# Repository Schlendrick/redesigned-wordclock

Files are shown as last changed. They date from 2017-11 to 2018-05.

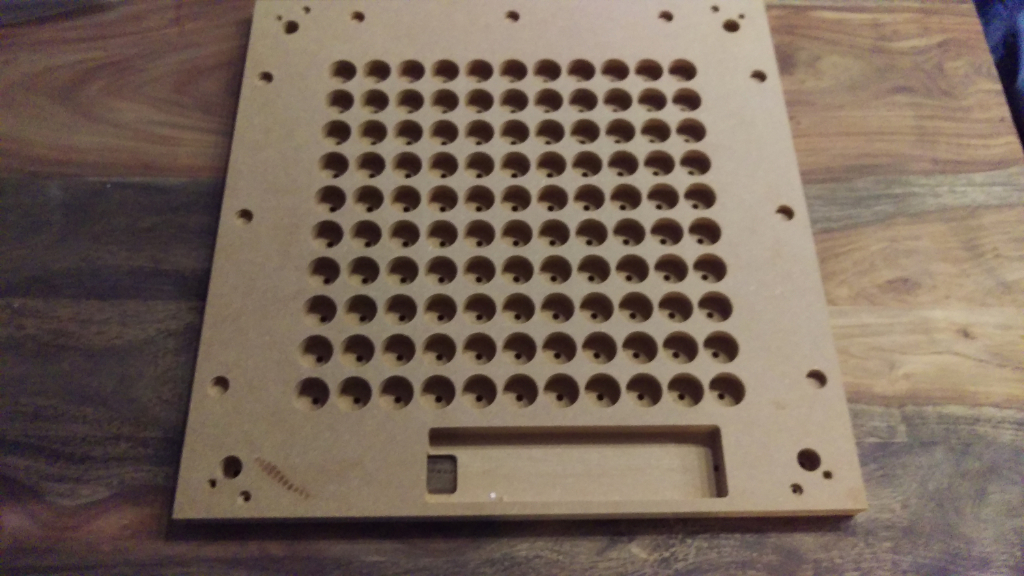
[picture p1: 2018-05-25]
Gehäuse/v1.0/IMAG0333.jpg

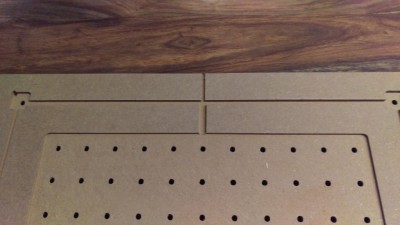
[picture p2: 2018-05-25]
Gehäuse/v1.0/IMAG0337.jpg

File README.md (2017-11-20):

# rgb_wordclock_redesigned

Wordclock based on the popular WS2812B RGB LED strips with the ESP32 Controller.

## ToDo

- [x] Replace DCF77 recipient (Onboard Wifi sync)
- [ ] Turn the clock automatic off at night
- [ ] Show the temperature (Onboard Temperatur Sensor)
- [ ] Smartphone app to control the clock
- [ ] Replace WS2812B to newer Version LED (e.g.WS2813) to save energy

## Build

## Known Issues

## LED Mapping

`alt_layout1.h`

```
111                                        110                      .                        .

       99 100 101 102 103 104 105 106 107 108 109                      E S K I S T A F Ü N F
       98  97  96  95  94  93  92  91  90  89  88                      Z E H N Z W A N Z I G
       77  78  79  80  81  82  83  84  85  86  87                      D R E I V I E R T E L
       76  75  74  73  72  71  70  69  68  67  66                      V O R F U N K N A C H
       55  56  57  58  59  60  61  62  63  64  65                      H A L B A E L F Ü N F
       54  53  52  51  50  49  48  47  46  45  44                      E I N S X Ä M Z W E I
       33  34  35  36  37  38  39  40  41  42  43                      D R E I A U J V I E R
       32  31  30  29  28  27  26  25  24  23  22                      S E C H S N L A C H T
       11  12  13  14  15  16  17  18  19  20  21                      S I E B E N Z W Ö L F
       10  9   8   7   6   5   4   3   2    1   0                      Z E H N E U N K U H R

112                                        113                      .                         .
```

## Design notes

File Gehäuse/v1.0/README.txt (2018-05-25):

MY EDIT:

http://diskussion.christians-bastel-laden.de/viewtopic.php?f=11&t=2673
"Nun aber ein Paar Bilder des gefrästen Rahmens. Material ist MDF in 22mm stärke und ausgelegt für ws2812b leds."

################
#    Lizenz    #
################

Dieser Rahmen wird unter der Creative Commons Lizenz "CC BY-NC-SA" veröffentlicht.
Diese Lizenz erlaubt es euch den Rahmen zu benutzen zu verändern, darauf aufzubauen und zu erweitern. Sämtliche Änderungen müssen jedoch unter der gleichen Lizenz mit Verweis auf diese Basis veröffentlicht und anderen zugänglich gemacht werden.

Eine kommerzielle Nutzung ist nicht gestattet.

Weiter Details zur Lizenz findet Ihr unter: https://creativecommons.org/licenses/by-nc-sa/4.0/

########################################
#    Aufbereitung für die Fertigung    #
########################################

Die Dateien sind für einen 50x50cm Rahmen.

Ihr findet im Archive 2 DXF Dateien. In den Dateien sind die einzelnen Bereiche des Rahmens gruppiert. Hier findet ihr nun die jeweiligen Zieltiefen für die jeweiligen Ebenen. Diese Daten benötigt ihr zum vorbereiten der Zeichnung zum fräsen auf eurer Fräse.

Bei den Zieltiefen gehe ich von einer 22mm starken MDF Platte aus.

Tiefe 0 = Plan mit Oberfläche. Tiefe -22 = komplett durchgefräst.

Datei: Wortuhr_rahmen_front_ws2812b.dxf

 - Aufhaengung aussen	: Zieltiefe -5 mm
 - Aufhaengung innen	: Zieltiefe -22 mm
 - LED			: Zieltiefe -20 mm(gefräst von vorne), oder Zieltiefe -6.5mm wenn von der Rückseite gefräst
 - Minuten LED		: Zieltiefe -20 mm(gefräst von vorne), oder Zieltiefe -6.5mm wenn von der Rückseite gefräst
 - Lichtkegel		: Zieltiefe -16.5mm
 - Lichtkegel Minuten	: Zieltiefe -16.5mm
 - Magnete Aussen 	: Zieltiefe -3 mm
 - Magnete Innen	: Zieltiefe -8 mm
 - Elektronikbox	: Zieltiefe -19 mm

Datei: Wortuhr_rahmen_back.dxf

 - LED flaeche		: Zieltiefe -2.5 mm
 - Strombuchse		: Zieltiefe -3.5 mm
 - LDR Kanal	 	: Zieltiefe -2.5 mm
 - Kabelkanal		: Zieltiefe -2.5 mm
 - Elektronik		: Zieltiefe -19 mm

################
#    Donate    #
################

Sollte euch das Gehäuse gefallen, würde ich mich über ein Bier freuen. 

https://www.paypal.me/kstenders

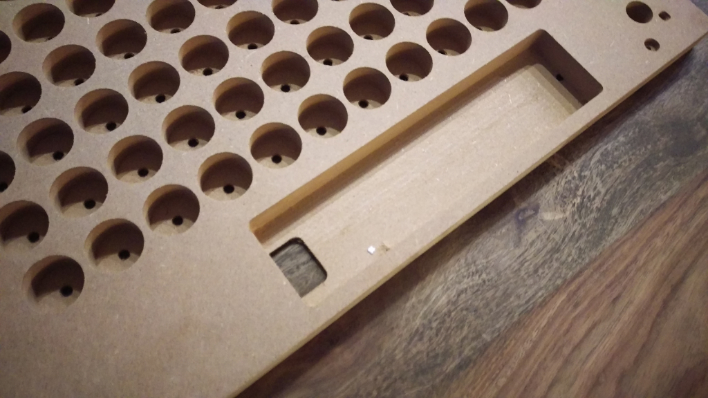
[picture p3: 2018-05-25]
Gehäuse/v1.0/IMAG0334.jpg

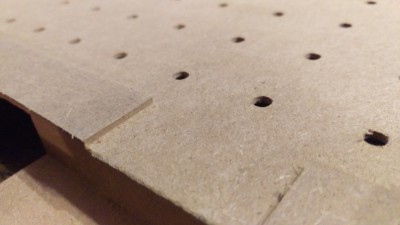
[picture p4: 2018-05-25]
Gehäuse/v1.0/IMAG0336.jpg

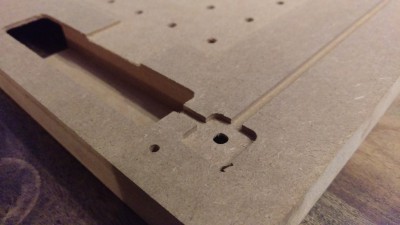
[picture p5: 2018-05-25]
Gehäuse/v1.0/IMAG0335.jpg

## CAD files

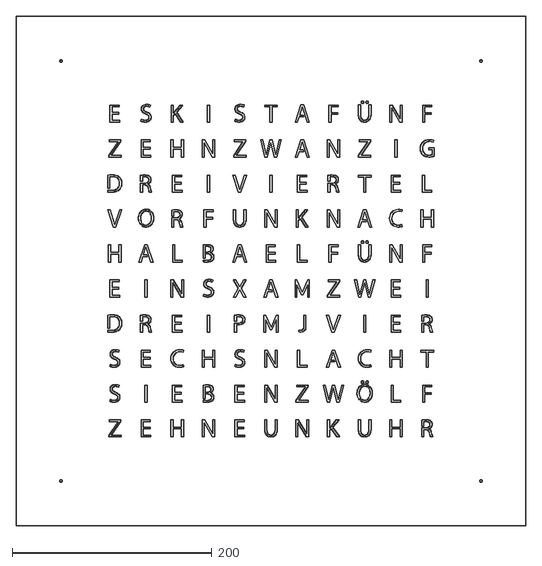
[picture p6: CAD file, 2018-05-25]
Frontplatte/500x500 DE mit 4mm Rand/500x500_CLT_DE_Laser_4_rand.dxf
510.0 x 510.0

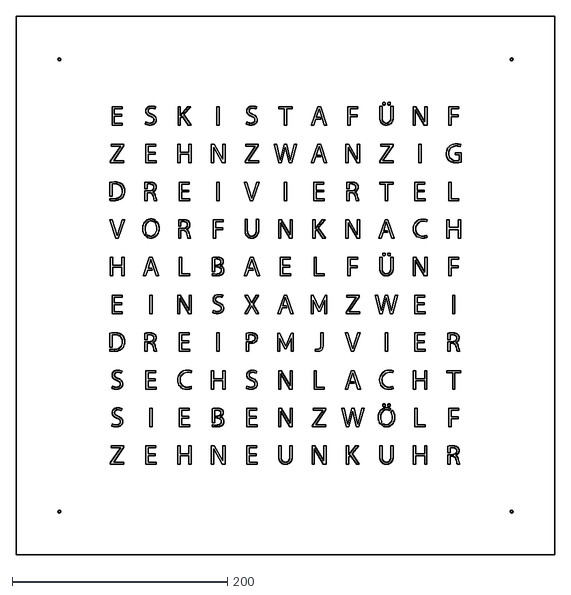
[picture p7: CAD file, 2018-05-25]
Frontplatte/500x500_CLT_DE_Laser/500x500_CLT_DE_Laser_4.dxf
500.0 x 500.0

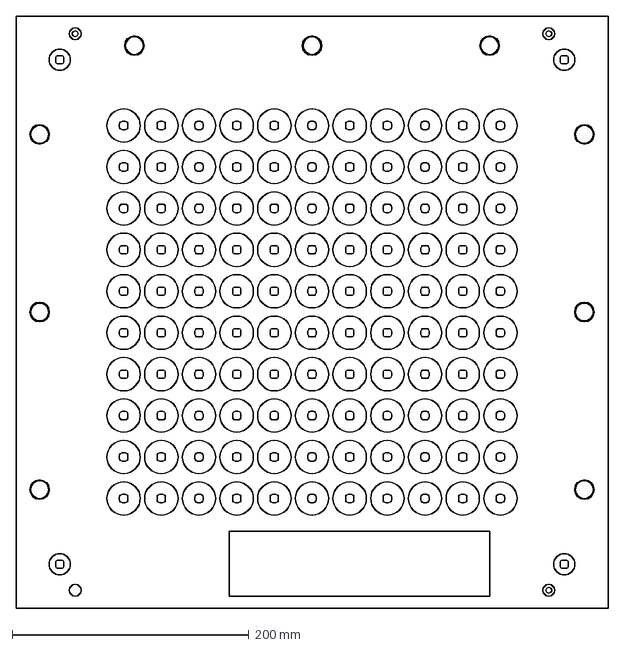
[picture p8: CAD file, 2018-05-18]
Gehäuse/v1.0/Wortuhr_rahmen_front_ws2812b.dxf
500.0 x 500.0 mm

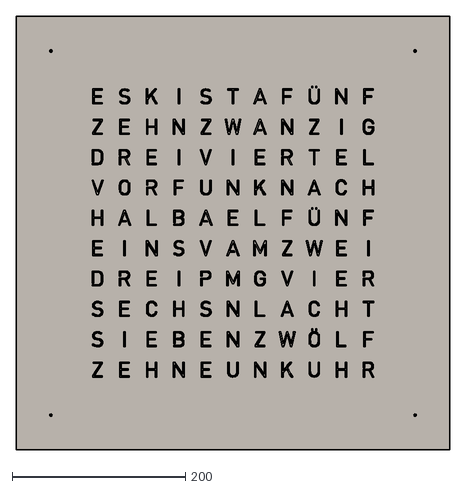
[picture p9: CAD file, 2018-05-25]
Frontplatte/500x500_CLT_DE_Laser/500x500_CLT_DE_Laser_7.dxf
500.0 x 500.0

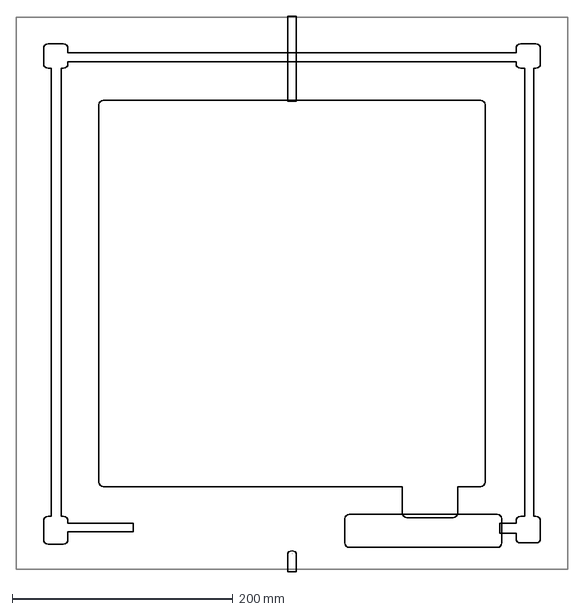
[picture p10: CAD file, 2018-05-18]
Gehäuse/v1.0/Wortuhr_rahmen_back.dxf
500.0 x 503.0 mm

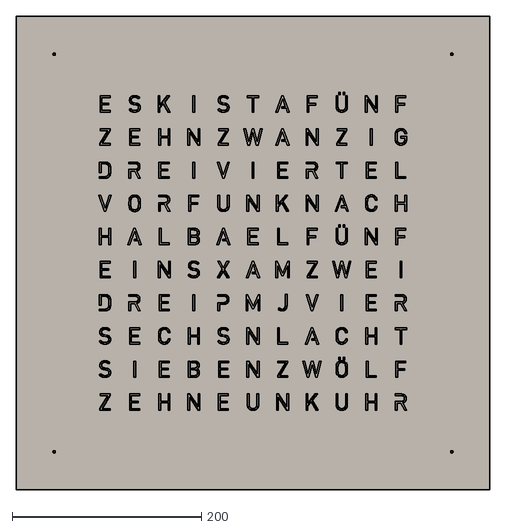
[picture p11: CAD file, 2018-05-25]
Frontplatte/500x500_CLT_DE_Laser/500x500_CLT_DE_Laser_1.dxf
500.0 x 500.0

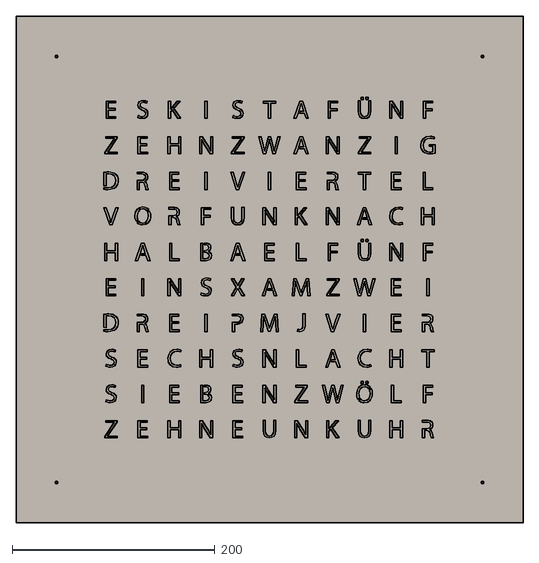
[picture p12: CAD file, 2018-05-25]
Frontplatte/500x500_CLT_DE_Laser/500x500_CLT_DE_Laser_6.dxf
500.0 x 500.0

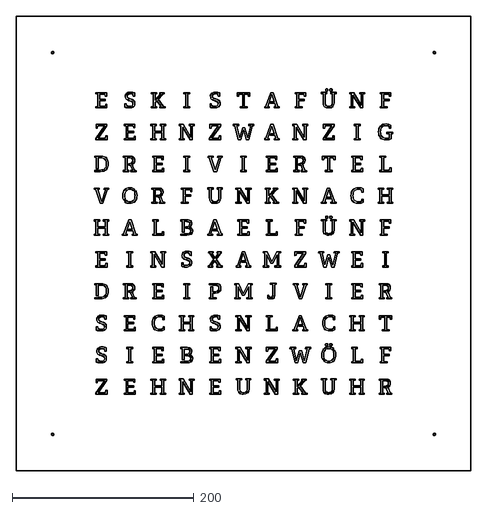
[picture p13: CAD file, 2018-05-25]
Frontplatte/500x500_CLT_DE_Laser/500x500_CLT_DE_Laser_2.dxf
500.0 x 500.0

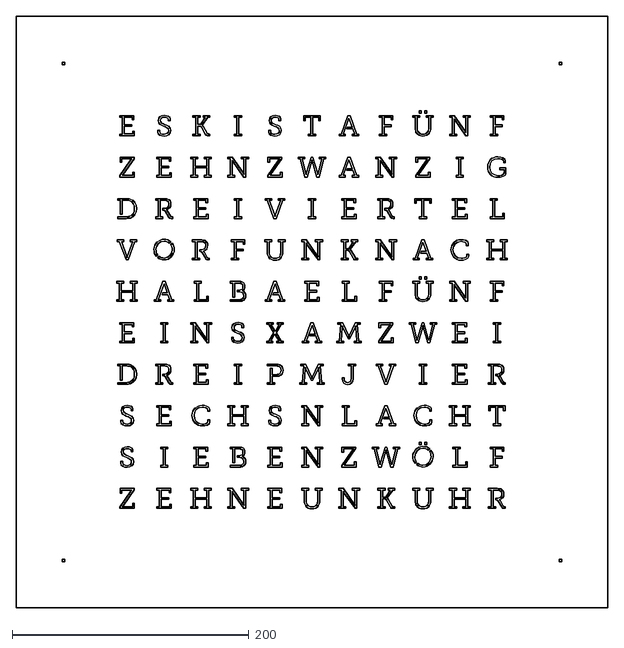
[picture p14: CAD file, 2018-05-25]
Frontplatte/500x500_CLT_DE_Laser/500x500_CLT_DE_Laser_5.dxf
500.0 x 500.0

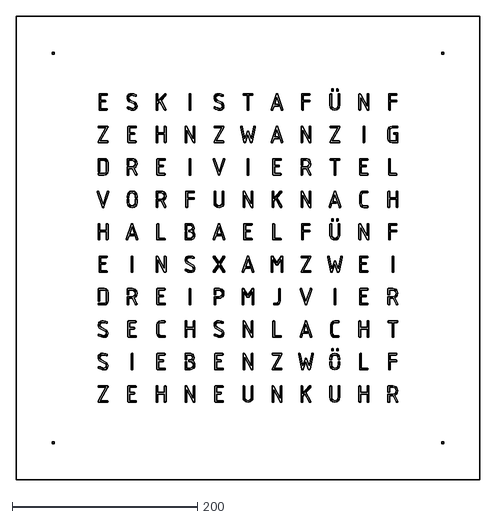
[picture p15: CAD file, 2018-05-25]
Frontplatte/500x500_CLT_DE_Laser/500x500_CLT_DE_Laser_3.dxf
500.0 x 500.0

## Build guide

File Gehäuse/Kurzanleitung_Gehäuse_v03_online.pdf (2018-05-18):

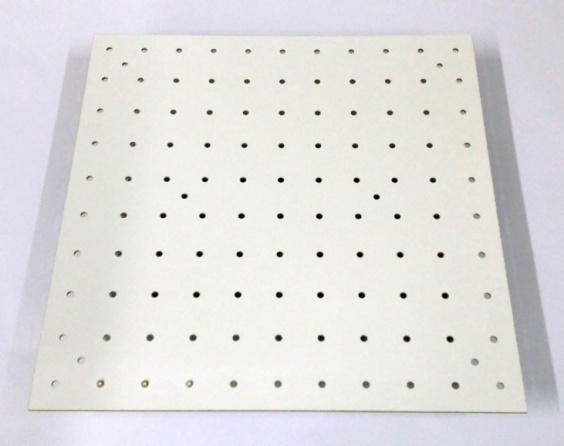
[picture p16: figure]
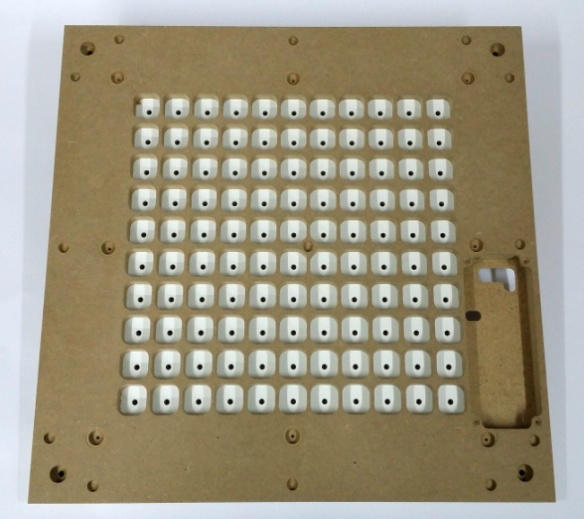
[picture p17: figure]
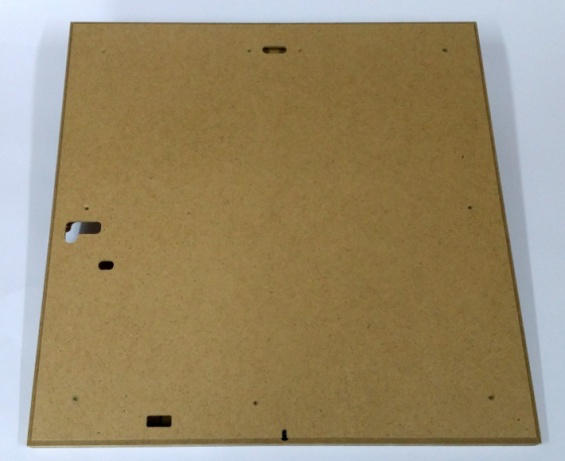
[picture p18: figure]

10.03.2015 1

# 45er v03 Gehäuse

Vielen Dank, dass Sie sich für dieses Gehäuse aus dem Hause Kellys Finest entschieden haben.

Ich wünsche Ihnen viel Freude an diesem Produkt.

Bevor Sie mit dem Bau beginnen:

- Lesen Sie vor der ersten Benutzung diese Anleitung sorgfältig durch. So werden Sie mit Ihrem neuen Gehäuse vertraut und erhalten wichtige Tipps für den Zusammenbau.
- Für Schäden die aus der Nichtbeachtung dieser Bedienungsanleitung verursacht werden, übernehmen wir keine Haftung.
- Beachten Sie besonders die Montagehinweise.
- Bewahren Sie diese Anleitung gut auf.

Lieferumfang 45er v03 Gehäuse:

- Gehäuse Korpus MDF 450x450x19mm
- LED Träger HDF 3mm
- Rückwand HDF 440x440x3mm
- 1 Anleitung

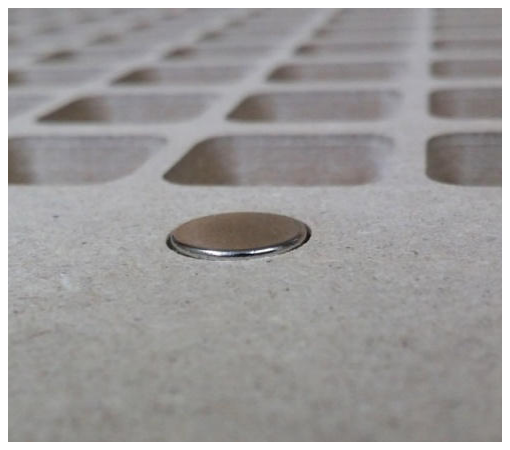
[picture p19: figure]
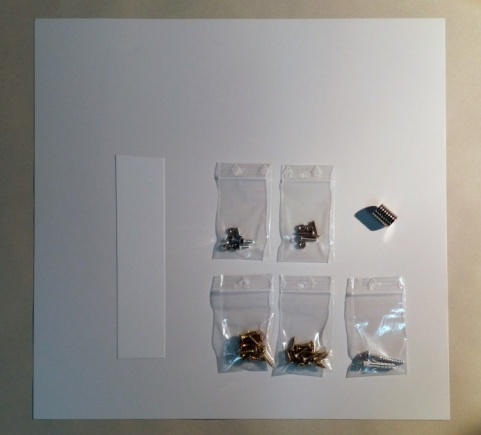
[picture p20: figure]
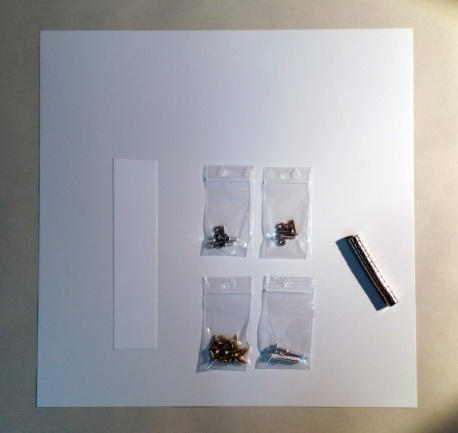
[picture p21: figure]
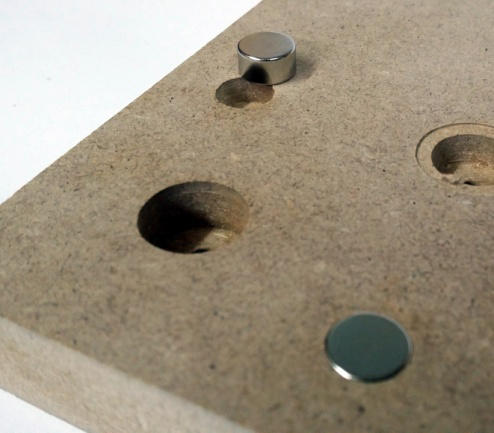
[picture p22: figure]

10.03.2015 2

zusätzlich im "45er v03 Gehäuse Zubehörpaket":

- Wandbefestigung Schraube + Dübel
- 8 Magnete Ø 12mm x 2mm
- 8x Schrauben als Basis für Magnete
- 9x Schrauben zur Rückwandbefestigung
- 6x Schrauben zur LED Trägerbefestigung
- 3x Linsenkopf Schrauben + Muttern für Tasterbetätigung
- 4x Senkkopf Schrauben + Muttern für v03 Befestigung
- Diffusionsfolie

oder im "45er -Stahl- v03 Gehäuse Zubehörpaket":

- Wandbefestigung Schraube + Dübel
- 13 Magnete Ø 10mm x 5mm
- 9x Schrauben zur Rückwandbefestigung
- 6x Schrauben zur LED Trägerbefestigung
- 3x Linsenkopf Schrauben + Muttern für Taster
- 4x Senkkopf Schrauben + Muttern für v03 Befestigung
- Diffusionsfolie

10.03.2015 3

Eigenschaften:

- passgenaues MDF Gehäuse zum Bau einer Wortuhr
- vom Gehäuse getrennter LED Träger, dadurch leichterer Aufbau und einfache Anpassbarkeit auf unterschiedliche LEDs --> mehr Passgenauigkeit
- speziell für 45ger Front mit v03 Nachbau Platine
- inklusive Rückwand zur Abdeckung/Schutz der Elektronik
- höhenjustierbare Aufnahme der Magneten. Der Abstand zur Front kann so eingestellt werden, das ein kleiner Luftspalt zwischen Gehäuse und Front vorhanden ist. Dadurch wird die Gefahr der Ablösung der Folie stark gemindert da kein permanenter Zug auf die Folie wirkt.
- durch die Verklebung der 2mm Magnete direkt auf der Front und die entsprechenden Vertiefungen im Gehäuse wird ein Formschluss erreicht und die Front kann nicht verrutschen
- oder wahlweise für schwere magnetische Fronten, Aufnahme für 13 stärkere Magnete zum Einkleben
- FTDI Anschluss zum Programmieren zugänglich von Hinten
- Standardmäßig zentraler Aufhängungspunkt zur Wandbefestigung

Mit Zubehörpaket zusätzlich:

- Satz Magnete Ø 12mm x 2mm für Befestigung einer Acrylfront (höhenverstellbar)
- oder Satz Magnete Ø 10mm x 5mm für schwere magnetische Fronten
- Hochwertige Diffusionsfolie für die Buchstabenmatrix und die Eck LEDs
- alle benötigten Schrauben zum Einbau der Elektronik und der Magnete
- Lösung um die Taster der v03 von außen bedienen zu können

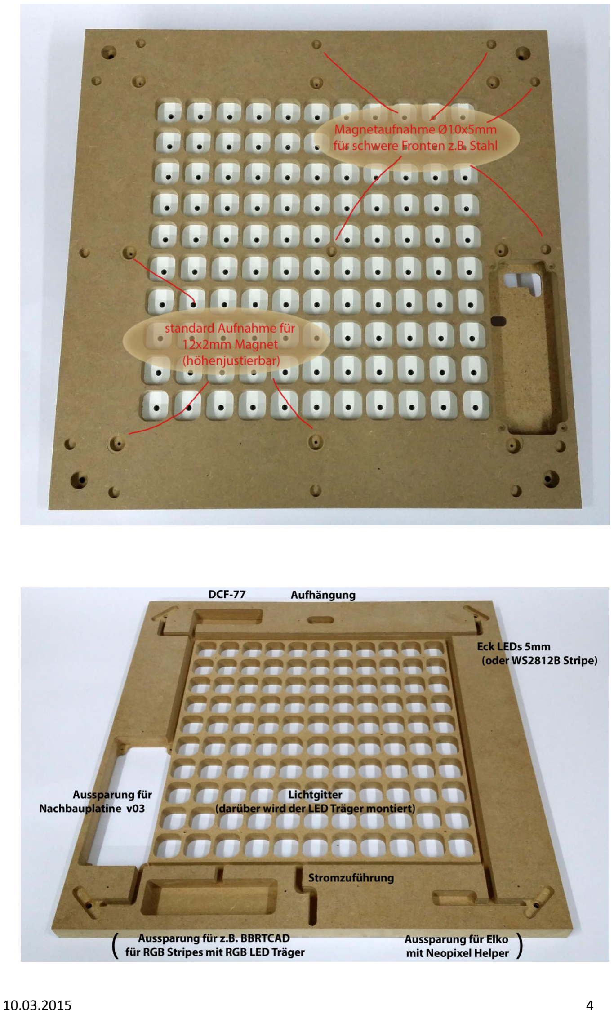
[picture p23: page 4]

10.03.2015 4

10.03.2015

### Magnete ! Hinweise für den sicheren Umgang

Verschlucken
Kinder können kleine Magnete verschlucken.
Wenn mehrere Magnete verschluckt werden, können die im Darm festsetzen und lebensgefährli
verursachen.
Magnete sind kein
nicht in die Hände von Kindern gelangen.

Elektroleitfähigkeit
Magnete sind aus Metall und leiten elektrischen Str Kinder können versuchen, Magnete in eine Steckdose und da
Magnete sind kein Spielzeug! Stellen Sie sicher, da nicht in die Hände von Kindern gelangen.

Quetschungen
Große Magnete haben eine sehr starke Anziehungskraf Bei unvorsichtiger Handhabung können Sie sich die F Haut
Quetschungen und Blutergüssen an den betroffenen St führen.
Knochenbrüche verurs
Tragen Sie bei der Handhabung von größeren Magneten

Herzschrittmacher
Magnete können die Funktion von Herzschrittmachern implantierten Defibrillatoren beeinflussen.
Ein Herzschrittmacher kann in den Testmodus geschal und Unwohlsein verursachen.
Ein Defibrillator funktioni
Halten Sie als Träger solcher Geräte einen genü
zu Magneten ein.
Warnen Sie Träger solcher Geräte vor der Annäherung

### Hinweise für den sicheren Umgang

Verschlucken
Kinder können kleine Magnete verschlucken.
Wenn mehrere Magnete verschluckt werden, können die
im Darm festsetzen und lebensgefährliche Komplikationen verursachen.
Magnete sind kein Spielzeug! Stellen Sie sicher, dass die Magnete nicht in die Hände von Kindern gelangen.

Elektroleitfähigkeit
Magnete sind aus Metall und leiten elektrischen Str Kinder können versuchen, Magnete in eine Steckdose bei einen Stromschlag erleiden.
Magnete sind kein Spielzeug! Stellen Sie sicher, da nicht in die Hände von Kindern gelangen.

Quetschungen
Große Magnete haben eine sehr starke Anziehungskraf Bei unvorsichtiger Handhabung können Sie sich die F zwischen zwei Magneten einklemmen. Das kann zu Quetschungen und Blutergüssen an den betroffenen St Sehr große Magnete können durch ihre Kraft Knochenbrüche verursachen.
dicke Schutzhandschuhe

Herzschrittmacher
Magnete können die Funktion von Herzschrittmachern implantierten Defibrillatoren beeinflussen.
Ein Herzschrittmacher kann in den Testmodus geschal und Unwohlsein verursachen.
Ein Defibrillator funktioniert unter Umständen nicht mehr. Halten Sie als Träger solcher Geräte einen genü
zu Magneten ein.
an Magnete.

5

se sich

om.
zu stecken

ss die Magnete

t.
inger oder

ellen

und

tet werden

n nicht mehr.
genden Abstand

10.03.2015

Schwere Gegenstände
Zu hohe oder ruckartige Belastungen, Ermüdungsersch sowie Materialf
oder Magneth
Herunterfallende Gegenstände können zu
führen.
Die angegebene Haftkraft wird nur unter idealen Bed erreicht. Rechnen Sie ein
Verwenden Sie Magnete nicht an Orten, wo bei Materi kommen können.

Metall
Neodym
können sie zersplittern.
Scharfkantige Splitter können meter
we
Vermeide
Tragen Sie bei der Handhabung von größe Schutzbrille.
Achten Sie darauf, dass umstehende Personen ebenfal

Magnetisches Feld
Magnete erzeugen ein weit reichendes, starkes Magne können unter anderem Fernseher und Laptops, Compute Festplatten, Kreditkarten und EC
mechanische Uhren, Hörgeräte und Lautsprecher besch Halten
die durch starke
Beachten Sie unsere Tabelle mit empfohlenen Abständ

Schwere Gegenstände
Zu hohe oder ruckartige Belastungen, Ermüdungsersch
sowie Materialfehler können dazu führen, dass sich ein Magnet oder Magnethaken von seinem Haftgrund löst. Herunterfallende Gegenstände können zu schweren Verletzungen

Die angegebene Haftkraft wird nur unter idealen Bed
erreicht. Rechnen Sie einen hohen Sicherheitsfaktor ein. alversagen Personen zu Schaden

-Splitter
Neodym-Magnete sind spröde. Wenn zwei Magnete kollidieren, können sie zersplittern.
Scharfkantige Splitter können meterweit weg geschleudert rden und Ihre Augen verletzen.
Vermeiden Sie Kollisionen von Magneten.
Tragen Sie bei der Handhabung von größeren Magneten eine Schutzbrille.
ls geschützt sind oder Abstand halten.

Magnetisches Feld
Magnete erzeugen ein weit reichendes, starkes Magne können unter anderem Fernseher und Laptops, Compute Festplatten, Kreditkarten und EC-Karten, Datenträger, mechanische Uhren, Hörgeräte und Lautsprecher besch Sie Magnete von allen Geräten und Gege
die durch starke Magnetfelder beschädigt werden können. en.

6

einungen

schweren Verletzungen

ingungen

ren Magneten eine

tfeld. Sie
r-

ädigen.
nständen fern,

10.03.2015 7

### Achtung, Montagehinweis:

Bitte beachten Sie vor der Montage folgende Hinweise,

- Die Kernbohrungen für die Schrauben zur Magnetaufnahme sind für Schnellbauschrauben mit dem Durchmesser 4mm gewählt
- Die Kernbohrungen für die Schrauben zur Rückwandbefestigung sind für Schnellbauschrauben mit dem Durchmesser 3mm gewählt
- Die Kernbohrungen für die Schrauben zur Befestigung des Lichtträgers sind für Schnellbauschrauben mit dem Durchmesser 3mm gewählt
- Ein Kabelauslass zur Stromversorgung ist angedeutet aber nicht nach unten ausgeführt um alle Möglichkeiten offen zu halten. Bei Bedarf kann der, an dieser Stelle, dünnwandige Rahmen unten mit einer Bohrung versehen werden.

### Wichtig!

- Die Verschraubung in MDF ist zwar stabil und völlig ausreichend aber man muss alle Schrauben mit viel Gefühl anziehen. Nur ganz leicht anziehen bis nichts mehr wackelt. Das genügt und hält.

### Magnete!

Achtung, Magnete sind sehr spröde. Achten Sie darauf das die Magnete nicht aus Versehen "zusammenschnappen", sie können dabei brechen.

Zum Trennen der aneinander liegenden Magnete schieben Sie sie am besten seitlich auseinander (Scheren). Wichtig dabei ist, dass Sie beide Magnete gut festhalten, damit sie sich nicht gleich wieder verbinden und Ihre Finger einklemmen oder zerbrechen. Benützen Sie dabei keine harten oder scharfen Gegenstände, diese können die Magnete beschädigen.

Tipp! vor dem Einlegen des Magneten Frischhaltefolie unter den Magneten legen. Damit kann beim Verkleben kein Klebstoff aufs Gehäuse laufen und aus Versehen die Magnete ins Gehäuse kleben.

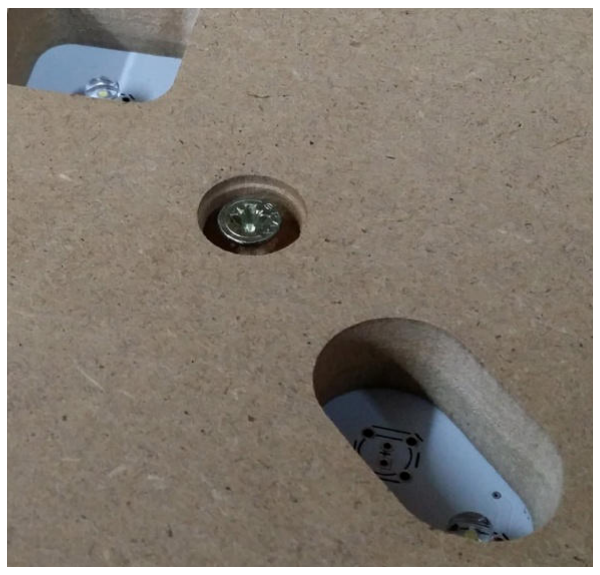
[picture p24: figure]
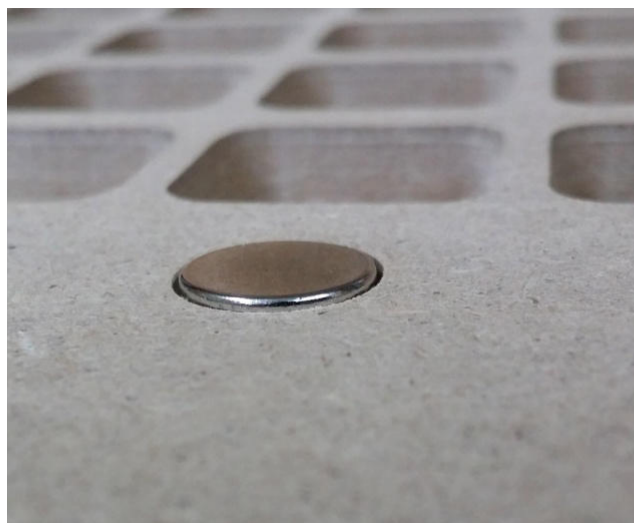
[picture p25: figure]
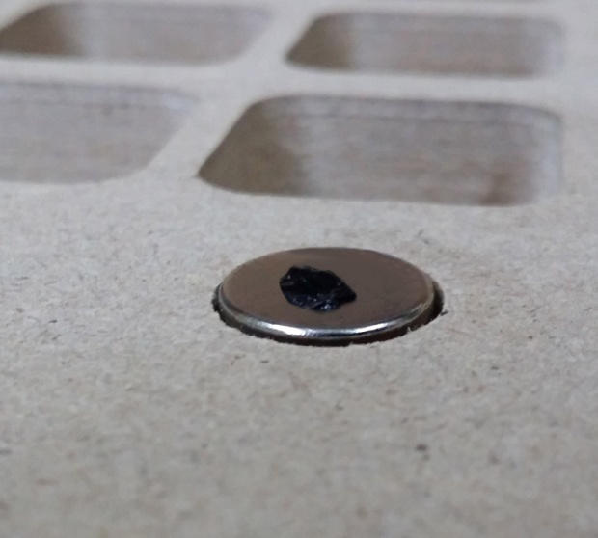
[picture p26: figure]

10.03.2015 8

Einbau der Magnete - Variante A:

Die Schrauben zur Magnetaufnahme(4 x 16mm) so weit eindrehen das sie ca. 1,5mm unterhalb der Oberfläche liegen

Ø 12mm x 2mm Magnete einlegen. Sicherstellen das jeder Magnet ca. 0,5mm über die Oberfläche des Gehäuses hinausragt um genügend Platz für die Diffusionsfolie zu lassen und um die Front mit ein wenig Luft, spannungsfrei Montieren zu können.
Tipp! nach dem Verkleben der Magnete muss noch ein Platt Papier zwischen Gehäuse und Front passen, dann liegen die Magnete gut auf und nichts ist verspannt.

Auf jeden Magneten einen kleinen Tropfen Klebstoff geben ("Silikon zum Kleben" hat sich bei mir bewährt oder Uhu Endfest 300) Aufpassen das es auch wirklich nur ein kleiner Tropfen ist und nicht beim zusammendrücken über den Rand hinausläuft und den Magnet ins Gehäuse einklebt.

Nun die Front passend auf das Gehäuse legen und andrücken. Man sollte nur aufpassen das man die Front gleich gut zentriert auflegt, da ein Verschieben dann nur bedingt möglich ist.

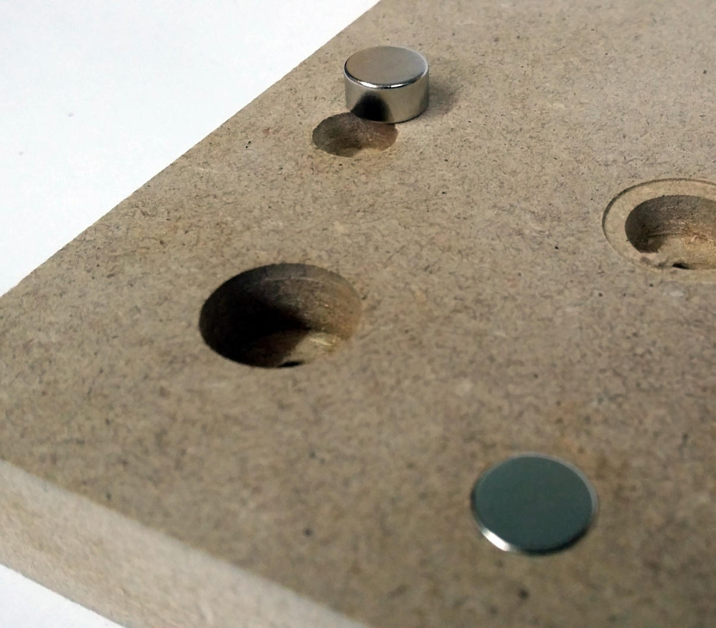
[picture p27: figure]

10.03.2015 9

Variante B:

- Ø 10mm x 5mm Magnete in die entsprechenden Öffnungen pressen. Hier wieder aufpassen, die Magnete können leicht brechen, evtl. ein Stück Holz unterlegen beim Einpressen um die Magnete nicht zu beschädigen.
- Darauf achten das die Magnete ein wenig herausschauen um Platz für die Diffusionsfolie zu lassen. Evtl. mit etwas Klebstoff sichern.
- Da hier kein Formschluss besteht, darauf achten das die Front nicht abrutscht. Evtl. zusätzlich sichern.
- Tipp! Wenn man die Magnete später wieder entfernen möchte, kann man in die Vertiefungen für die 10mm Magnete noch ein kleines Loch bohren (durch bohren). So hat man die Möglichkeit die Magnete später wieder von hinten heraus zu drücken.

Für den Fall das die gewählte Front bereits Metallplätchen aufgeklebt hat sind im Gehäuse um die Magnete herum zusätzliche Vertiefungen angebracht. Somit kann Variante A auch für Kauf-Fronten erweitert werden.

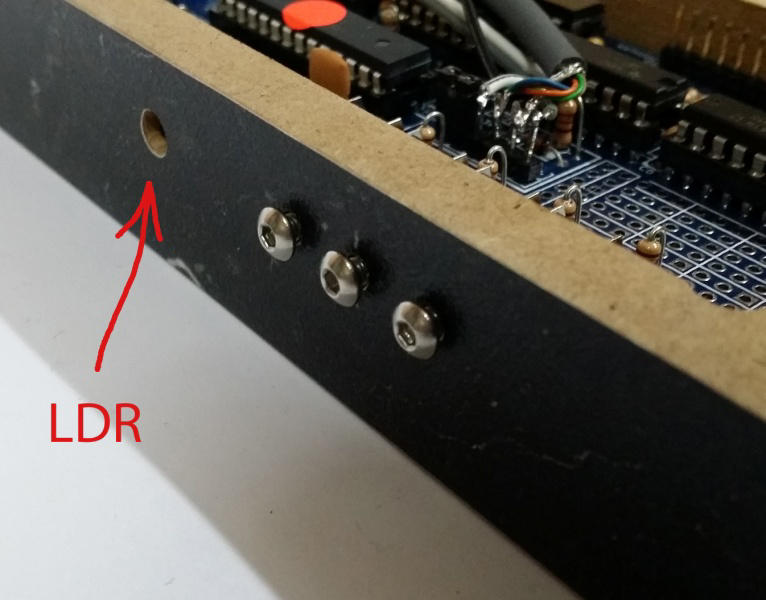
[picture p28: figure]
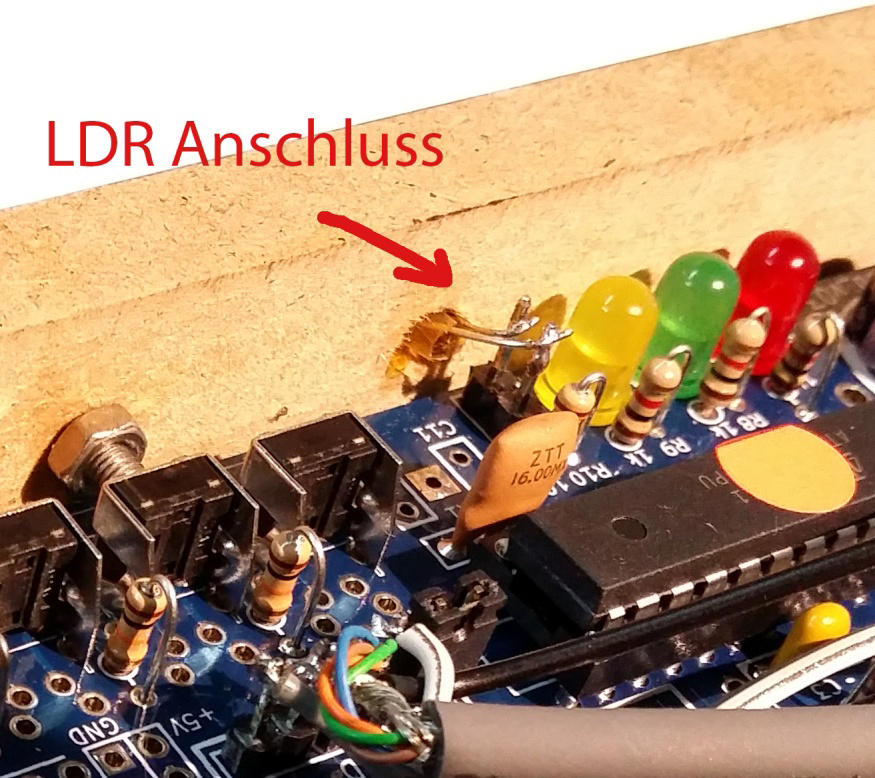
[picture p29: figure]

10.03.2015 10

Helligkeitssensor LDR

Der Helligkeitssensor lässt sich am einfachsten verbauen in dem man gleich neben dem Anschlusspunkt auf der Platine ein Loch ins Gehäuse bohrt um dort den Sensor zu verstauen.

Für die Bohrung nimmt man
einen 6mm Bohrer, dann hakt nichts.
Bohrung auf Höhe des
Anschlusspunktes der Platine mittig ins Gehäuse bohren.

Den LDR Sensor kann man direkt an den Pfostenstecker löten, so dass der Sensor ein paar Millimeter in die Bohrung im Gehäuse hinein ragt. Dann lässt er sich beim Montieren der Platine leicht in das Bohrloch einführen.

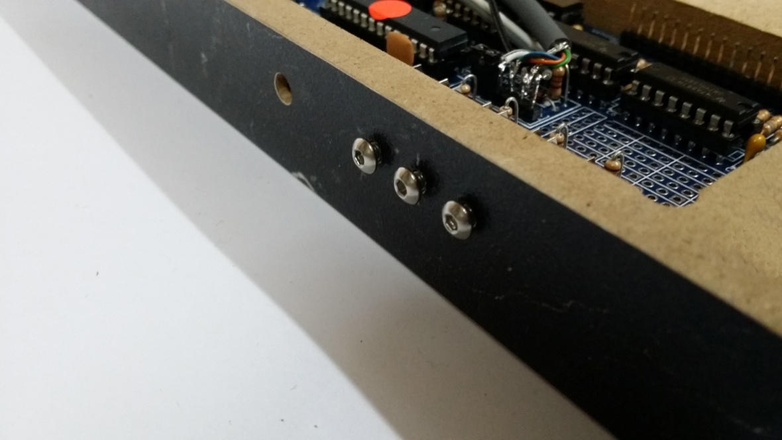
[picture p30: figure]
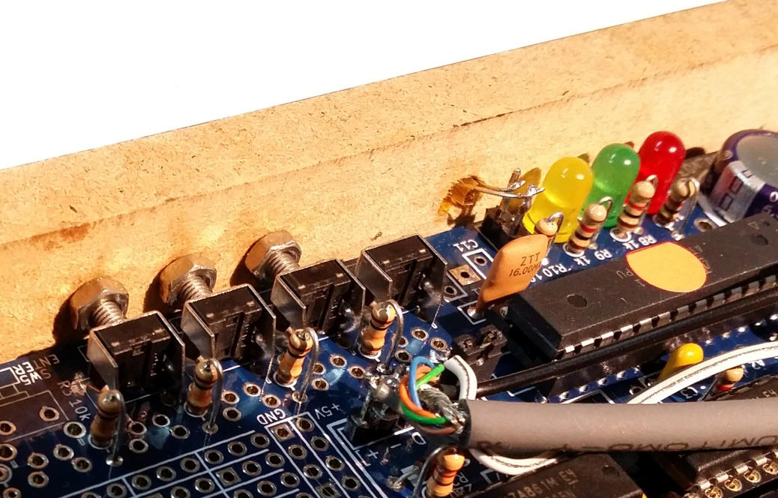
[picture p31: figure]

10.03.2015 11

Taster für v03

Eine bewährte Methode die Taster der Nachbauplatine v03 zu bedienen bzw. nach außen zu verlegen ist es, Schrauben mit Linsenkopf zu montieren (3x12mm). Diese werden durch entsprechend gebohrte Löcher im Rahmen gesteckt und von innen mit einer Mutter gekontert. Ein kleiner Tropfen Schraubensicherungslack oder Nagellack sichert das Ganze. (Aber aufpassen das die Schrauben oder Taster nicht verkleben)

Drei Löcher genügen (Mode, Stunde, Minute). Die Löcher so bohren das sie genau gegenüber der Taster liegen. Dann die Schrauben einstecken und mit den Muttern so sichern das die Schrauben gerade so viel Spiel haben um gut zu sitzen aber nicht die Taster dauernd drücken.

10.03.2015 12

Technische Spezifikation:

- Maße LxBxT: 45cm x 45cm x 1.9cm
- Material: MDF

Entsorgung von Verpackungsmaterial:

Das Verpackungsmaterial führen Sie bitte entweder, innerhalb Deutschlands, Ihrem Händler oder dem Entsorgungssystem Ihrer Gemeinde zu.

Technische Änderungen und Irrtümer vorbehalten. Stand 03/2015

ein Produkt der Firma Kellys Finest - UG (haftungsbeschränkt)

Martin-von-Deutinger-Str. 3e | 85456 Wartenberg | Germany
Telefon +49 8762 72915-40 | Fax: +49 8762 72915-32

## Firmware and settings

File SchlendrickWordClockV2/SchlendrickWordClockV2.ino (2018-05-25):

#include <Wire.h> //https://www.arduino.cc/en/Reference/Wire
#include <LiquidCrystal_I2C.h> //https://github.com/fdebrabander/Arduino-LiquidCrystal-I2C-library
#include <DS3232RTC.h> //https://github.com/JChristensen/DS3232RTC
#include <Bounce2.h> //https://github.com/thomasfredericks/Bounce2
#include <SimpleTimer.h> //https://github.com/jfturcot/SimpleTimer
#include <FAB_LED.h> //https://github.com/sonyhome/FAB_LED
#include <DHT.h> //https://github.com/adafruit/DHT-sensor-library
#include <Adafruit_Sensor.h> //https://github.com/adafruit/Adafruit_Sensor
//#include <DCF77.h>
//#include <TimeLib.h>

//define adresses
#define DS3231_ADDRESS 0x68
#define BUTTON_HOUR 8
#define BUTTON_MIN 9
#define BUTTON_MODE 10
#define LEDPIN 6
#define DHTPIN 7
#define LDRPIN A1
//#define DCF_PIN 2           // Connection pin to DCF 77 device
//#define DCF_INTERRUPT 0    // Interrupt number associated with pin

//define wordclock modes
#define CLOCK_LDR 0
#define CLOCK_100_PER_MODE 1
#define TEMPERATUR_MODE 2
#define HEART_MODE 3
#define OFF_MODE 4

// Declare the LED protocol and the port
sk6812<D, LEDPIN>  strip;
//ws2812b<D, 6>  strip;

/* ************** DCF BLOCK ************** */
//time_t time;
//DCF77 DCF = DCF77(DCF_PIN, 0);

/* ************** LED BLOCK ************** */
// How many pixels to control
const uint8_t numPixels = 115;
// The pixel array to display
rgbw pixels[numPixels] = {};
// define brightness var
uint8_t ledBrightness = 255;

/* ************** TEMP BLOCK ************** */
#define DHTTYPE DHT11   // DHT 11
DHT dht(DHTPIN, DHTTYPE);
float roomTemperature;

/* ************** LCD BLOCK ************** */
// Set the LCD address to 0x27 for a 16 chars and 2 line display
LiquidCrystal_I2C lcd(0x27, 16, 2);

/* ************** BUTTON BLOCK ************** */
//define Bouncer & delay variables
Bounce debouncerHour = Bounce();
Bounce debouncerMin = Bounce();
Bounce debouncerMode = Bounce();
bool bolMinSet = false;
bool bolHourSet = false;
bool bolModeSet = false;
int modeSelector = 0;

/* ************** SERIAL BLOCK ************** */
int serialOutputCounter = 0;

/* ************** TIMER BLOCK ************** */
//define Timer
SimpleTimer timerClock;
SimpleTimer timerTemp;

void setup()
{
  // Turn off the LEDs
  strip.clear(2 * numPixels);

  //intialize RTC
  setSyncProvider(RTC.get);   // the function to get the time from the RTC
  if (timeStatus() != timeSet)
    Serial.println("Unable to sync with the RTC");
  else
    Serial.println("RTC has set the system time");

  //intialize DCF
  //DCF.Start();

  //start output Timer
  timerClock.setInterval(100, processTimesOutput);
  timerTemp.setInterval(5000, getTemperatures);


  //intialize wire
  Wire.begin();

  //intialize serial
  Serial.begin(9600);

  // Setup the button with an internal pull-up, attach bouncer , set bounceinterval
  pinMode(BUTTON_HOUR, INPUT_PULLUP);
  debouncerHour.attach(BUTTON_HOUR);
  debouncerHour.interval(5); // interval in ms
  pinMode(BUTTON_MIN, INPUT_PULLUP);
  debouncerMin.attach(BUTTON_MIN);
  debouncerMin.interval(5); // interval in ms
  pinMode(BUTTON_MODE, INPUT_PULLUP);
  debouncerMode.attach(BUTTON_MODE);
  debouncerMode.interval(5); // interval in ms

  //initialize temps
  dht.begin();
  getTemperatures();
  if (isnan(roomTemperature)) {
    Serial.println("Failed to read from DHT sensor!");
    return;
  }

  // initialize the LCD
  lcd.begin();
  lcd.backlight();
}

void loop()
{
  //run timer (check)
  timerClock.run();
  timerTemp.run();
  checkButtons();
}

////////////////////////////////////////////////////////////////////////////////
// Calculate LED
////////////////////////////////////////////////////////////////////////////////
void calculateAndPushLED () {
  //reset all leds to "dark"
  for (int i = 0; i < numPixels; i++) {
    //pre define every led as "off"
    updateLED(i, 0, 0 , 0, 0);
  }

  switch (modeSelector) {
    case CLOCK_100_PER_MODE:
      ledBrightness = 255;
      generateClockMatrix();
      break;
    case CLOCK_LDR: //25 so dass sicher im positiven Bereich
      ledBrightness = 25 + ((1000 - analogRead(LDRPIN)) / 4);
      generateClockMatrix();
      break;
    case TEMPERATUR_MODE:
      ledBrightness = 255;
      generateTempMatrix();
      break;
    case HEART_MODE:
      ledBrightness = 255;
      pushHeart();
      break;
    case OFF_MODE:
      //Nothing
      break;
      /*
        case ALL_ON_MODE:
        for (int i = 0; i < numPixels; i++) {
        //pre define every led as "off"
        updateLED(i, 0, 0 , 0, 111);
        }
      */
      break;
  }

  //activate matrix on hardware
  strip.sendPixels(numPixels, pixels);
}

////////////////////////////////////////////////////////////////////////////////
// Generate Clock Matrix
////////////////////////////////////////////////////////////////////////////////
void generateClockMatrix() {
  //Update LED (ID, R, G, B, White)
  pushES_IST();

  //prepair time
  int myMin = minute();
  int myHour = hour();

  if (myMin >= 25) // USE CASE "VOR"/"HALB"
    myHour += 1;
  if (myHour >= 12) // 24h auf 12h brechen
    myHour -= 12;


  //calculate hours
  switch (myHour) {
    case 0: pushZWOELF(); break;
    case 1: if (myMin > 4) {
        pushEINS();
      } else {
        pushEIN();
      } break;
    case 2: pushZWEI(); break;
    case 3: pushDREI(); break;
    case 4: pushVIER(); break;
    case 5: pushFUENF2(); break;
    case 6: pushSECHS(); break;
    case 7: pushSIEBEN(); break;
    case 8: pushACHT(); break;
    case 9: pushNEUN(); break;
    case 10: pushZEHN(); break;
    case 11: pushELF(); break;
  }

  //calculate minutes
  switch (myMin) {
    case 0: case 1: case 2: case 3: case 4:
      pushUHR(); break;
    case 5: case 6: case 7: case 8: case 9:
      pushFUENF1(); pushNACH(); break;
    case 10: case 11: case 12: case 13: case 14:
      pushZEHN1(); pushNACH(); break;
    case 15: case 16: case 17: case 18: case 19:
      pushVIERTEL(); pushNACH(); break;
    case 20: case 21: case 22: case 23: case 24:
      pushZWANZIG(); pushNACH(); break;
    case 25: case 26: case 27: case 28: case 29:
      pushFUENF1(); pushVOR(); pushHALB(); break;
    case 30: case 31: case 32: case 33: case 34:
      pushHALB(); break;
    case 35: case 36: case 37: case 38: case 39:
      pushFUENF1(); pushNACH(); pushHALB(); break;
    case 40: case 41: case 42: case 43: case 44:
      pushZWANZIG(); pushVOR(); break;
    case 45: case 46: case 47: case 48: case 49:
      pushVIERTEL(); pushVOR(); break;
    case 50: case 51: case 52: case 53: case 54:
      pushZEHN1(); pushVOR(); break;
    case 55: case 56: case 57: case 58: case 59:
      pushFUENF1(); pushVOR(); break;
  }

  //calculate sinlge dots (corner-minutes)
  int singleMinutes = myMin % 5;
  switch (singleMinutes) {
    case 1: pushONE(); break;
    case 2: pushONE(); pushTWO(); break;
    case 3: pushONE(); pushTWO(); pushTHREE(); break;
    case 4: pushONE(); pushTWO(); pushTHREE(); pushFOUR(); break;
  }
}

////////////////////////////////////////////////////////////////////////////////
// Generate Temprature Matrix
////////////////////////////////////////////////////////////////////////////////
void generateTempMatrix() {
  int secondDigit = (int)roomTemperature % 10;
  int firstDigit = ((int)roomTemperature - secondDigit) / 10;

  pushTempDegree();

  switch (firstDigit) {
    case 1: pushTempLOne(); break;
    case 2: pushTempLTwo(); break;
    case 3: pushTempLThree(); break;
    case 4: pushTempLFour(); break;
  }
  switch (secondDigit) {
    case 0: pushTempRZero(); break;
    case 1: pushTempROne(); break;
    case 2: pushTempRTwo(); break;
    case 3: pushTempRThree(); break;
    case 4: pushTempRFour(); break;
    case 5: pushTempRFive(); break;
    case 6: pushTempRSix(); break;
    case 7: pushTempRSeven(); break;
    case 8: pushTempREight(); break;
    case 9: pushTempRNine(); break;
  }
}

////////////////////////////////////////////////////////////////////////////////
// Check if Buttons are pushed
////////////////////////////////////////////////////////////////////////////////
void checkButtons() {
  //Update Bouncer & gather button status
  debouncerHour.update();
  debouncerMin.update();
  debouncerMode.update();
  int buttonHour = debouncerHour.read();
  int buttonMin = debouncerMin.read();
  int buttonMode = debouncerMode.read();

  if (buttonHour == LOW && bolHourSet == false) {
    bolHourSet = true;
    setTime(hour() + 1, minute(), 0, 17, 7, 2017);
    RTC.set(now());
  } else if (buttonHour == HIGH) {
    bolHourSet = false;
  }

  if (buttonMin == LOW && bolMinSet == false) {
    bolMinSet = true;
    //check if time change would result in adding an hour
    if (minute() == 59)
      setTime(hour() - 1, minute() + 1, 0, 17, 7, 2017);
    else
      setTime(hour(), minute() + 1, 0, 17, 7, 2017);
    RTC.set(now());
  } else if (buttonMin == HIGH) {
    bolMinSet = false;
  }

  if (buttonMode == LOW && bolModeSet == false) {
    bolModeSet = true;

    //increment mode and reset if too high
    modeSelector++;
    if (modeSelector == 5)
      modeSelector = 0;
    Serial.println("MODE Selected: " + String(modeSelector));
  } else if (buttonMode == HIGH) {
    bolModeSet = false;
  }
}

////////////////////////////////////////////////////////////////////////////////
// Output the time to different media
////////////////////////////////////////////////////////////////////////////////
void processTimesOutput() {
  calculateAndPushLED();
  String rowOne = String(hour()) + ":" + String(minute()) + ":" + String(second()) + " | Mode" + modeSelector;
  String rowTwo = String(roomTemperature) + "\xDF" + "C " + String((1000 - analogRead(LDRPIN)) / 10) + "%LDR";
  printDebugOnLCD(rowOne, rowTwo);
  printDebugOnConsole(rowOne, rowTwo);
}

////////////////////////////////////////////////////////////////////////////////
// Write current Debug on LCD
////////////////////////////////////////////////////////////////////////////////
void printDebugOnLCD(String rowOne, String rowTwo) {
  for (int i = 0; i < (16 - rowTwo.length()); i++)
    rowOne += ' ';
  for (int i = 0; i < (16 - rowTwo.length()); i++)
    rowTwo += ' ';
  lcd.setCursor( 0, 0);
  lcd.print( rowOne );
  lcd.setCursor( 0, 1);
  lcd.print( rowTwo );
}

////////////////////////////////////////////////////////////////////////////////
// Write current Debug on console
////////////////////////////////////////////////////////////////////////////////
void printDebugOnConsole(String rowOne, String rowTwo) {
  getDCFTime();
  //cycle 0-9 for output to slow serial down
  serialOutputCounter++; if (serialOutputCounter > 9) serialOutputCounter = 0;
  if (serialOutputCounter == 0) {
    Serial.println( "******************" );
    Serial.println( rowOne );
    Serial.println( rowTwo );
  }
}

////////////////////////////////////////////////////////////////////////////////
// Get DCF Time
////////////////////////////////////////////////////////////////////////////////
void getDCFTime()  {
  /*
    time_t DCFtime = DCF.getTime(); // Check if new DCF77 time is available
    if (DCFtime != 0)
    {
      Serial.println("=================================================");
      Serial.println("Time is updated");
      Serial.println("=================================================");
      //setTime(DCFtime);
      printDebugOnLCD("Time is updated", "Time is updated");
    }
  */
}

////////////////////////////////////////////////////////////////////////////////
// Reads temperature sensor of DS3231&DHT11 and write to variable
////////////////////////////////////////////////////////////////////////////////
void getTemperatures() {
  // Reading temperature or humidity takes about 250 milliseconds!
  // Sensor readings may also be up to 2 seconds 'old' (its a very slow sensor)
  //float h = dht.readHumidity();
  // Read temperature as Celsius (the default)
  roomTemperature = dht.readTemperature();
}

////////////////////////////////////////////////////////////////////////////////
// Sets the led to specified color (ledID/R/G/B/White)
////////////////////////////////////////////////////////////////////////////////
void updateLED(int i, char r, char g, char b, char w)
{
  pixels[i].r = g; //fix some errors with strip?
  pixels[i].g = r; //fix some errors with strip?
  pixels[i].b = b;
  pixels[i].w = w;
}

////////////////////////////////////////////////////////////////////////////////
// PUSHES FOR STRIP
////////////////////////////////////////////////////////////////////////////////
void pushES_IST()  {
  updateLED(99, 0, 0, 0, ledBrightness);
  updateLED(100, 0, 0, 0, ledBrightness);
  updateLED(102, 0, 0, 0, ledBrightness);
  updateLED(103, 0, 0, 0, ledBrightness);
  updateLED(104, 0, 0, 0, ledBrightness);
}
void pushFUENF1() {
  updateLED(106, 0, 0, 0, ledBrightness);
  updateLED(107, 0, 0, 0, ledBrightness);
  updateLED(108, 0, 0, 0, ledBrightness);
  updateLED(109, 0, 0, 0, ledBrightness);
}
void pushFUENF2() {
  updateLED(62, 0, 0, 0, ledBrightness);
  updateLED(63, 0, 0, 0, ledBrightness);
  updateLED(64, 0, 0, 0, ledBrightness);
  updateLED(65, 0, 0, 0, ledBrightness);
}
void pushNACH() {
  updateLED(69, 0, 0, 0, ledBrightness);
  updateLED(68, 0, 0, 0, ledBrightness);
  updateLED(67, 0, 0, 0, ledBrightness);
  updateLED(66, 0, 0, 0, ledBrightness);
}
void pushZEHN1() {
  updateLED(98, 0, 0, 0, ledBrightness);
  updateLED(97, 0, 0, 0, ledBrightness);
  updateLED(96, 0, 0, 0, ledBrightness);
  updateLED(95, 0, 0, 0, ledBrightness);
}
void pushVIERTEL() {
  updateLED(81, 0, 0, 0, ledBrightness);
  updateLED(82, 0, 0, 0, ledBrightness);
  updateLED(83, 0, 0, 0, ledBrightness);
  updateLED(84, 0, 0, 0, ledBrightness);
  updateLED(85, 0, 0, 0, ledBrightness);
  updateLED(86, 0, 0, 0, ledBrightness);
  updateLED(87, 0, 0, 0, ledBrightness);
}
void pushVOR() {
  updateLED(76, 0, 0, 0, ledBrightness);
  updateLED(75, 0, 0, 0, ledBrightness);
  updateLED(74, 0, 0, 0, ledBrightness);
}
void pushHALB() {
  updateLED(55, 0, 0, 0, ledBrightness);
  updateLED(56, 0, 0, 0, ledBrightness);
  updateLED(57, 0, 0, 0, ledBrightness);
  updateLED(58, 0, 0, 0, ledBrightness);
}
void pushONE() {
  updateLED(111, 0, 0, 0, ledBrightness);
}
void pushTWO() {
  updateLED(110, 0, 0, 0, ledBrightness);
}
void pushTHREE() {
  updateLED(113, 0, 0, 0, ledBrightness);
}
void pushFOUR() {
  updateLED(112, 0, 0, 0, ledBrightness);
}
void pushZWANZIG() {
  updateLED(94, 0, 0, 0, ledBrightness);
  updateLED(93, 0, 0, 0, ledBrightness);
  updateLED(92, 0, 0, 0, ledBrightness);
  updateLED(91, 0, 0, 0, ledBrightness);
  updateLED(90, 0, 0, 0, ledBrightness);
  updateLED(89, 0, 0, 0, ledBrightness);
  updateLED(88, 0, 0, 0, ledBrightness);
}
void pushZWOELF() {
  updateLED(17, 0, 0, 0, ledBrightness);
  updateLED(18, 0, 0, 0, ledBrightness);
  updateLED(19, 0, 0, 0, ledBrightness);
  updateLED(20, 0, 0, 0, ledBrightness);
  updateLED(21, 0, 0, 0, ledBrightness);
}
void pushEINS() {
  updateLED(54, 0, 0, 0, ledBrightness);
  updateLED(53, 0, 0, 0, ledBrightness);
  updateLED(52, 0, 0, 0, ledBrightness);
  updateLED(51, 0, 0, 0, ledBrightness);
}
void pushEIN() {
  updateLED(54, 0, 0, 0, ledBrightness);
  updateLED(53, 0, 0, 0, ledBrightness);
  updateLED(52, 0, 0, 0, ledBrightness);
}
void pushZWEI() {
  updateLED(47, 0, 0, 0, ledBrightness);
  updateLED(46, 0, 0, 0, ledBrightness);
  updateLED(45, 0, 0, 0, ledBrightness);
  updateLED(44, 0, 0, 0, ledBrightness);
}
void pushDREI() {
  updateLED(33, 0, 0, 0, ledBrightness);
  updateLED(34, 0, 0, 0, ledBrightness);
  updateLED(35, 0, 0, 0, ledBrightness);
  updateLED(36, 0, 0, 0, ledBrightness);
}
void pushVIER() {
  updateLED(40, 0, 0, 0, ledBrightness);
  updateLED(41, 0, 0, 0, ledBrightness);
  updateLED(42, 0, 0, 0, ledBrightness);
  updateLED(43, 0, 0, 0, ledBrightness);
}
void pushSECHS() {
  updateLED(32, 0, 0, 0, ledBrightness);
  updateLED(31, 0, 0, 0, ledBrightness);
  updateLED(30, 0, 0, 0, ledBrightness);
  updateLED(29, 0, 0, 0, ledBrightness);
  updateLED(28, 0, 0, 0, ledBrightness);
}
void pushSIEBEN() {
  updateLED(11, 0, 0, 0, ledBrightness);
  updateLED(12, 0, 0, 0, ledBrightness);
  updateLED(13, 0, 0, 0, ledBrightness);
  updateLED(14, 0, 0, 0, ledBrightness);
  updateLED(15, 0, 0, 0, ledBrightness);
  updateLED(16, 0, 0, 0, ledBrightness);
}
void pushACHT() {
  updateLED(25, 0, 0, 0, ledBrightness);
  updateLED(24, 0, 0, 0, ledBrightness);
  updateLED(23, 0, 0, 0, ledBrightness);
  updateLED(22, 0, 0, 0, ledBrightness);
}
void pushNEUN() {
  updateLED(7, 0, 0, 0, ledBrightness);
  updateLED(6, 0, 0, 0, ledBrightness);
  updateLED(5, 0, 0, 0, ledBrightness);
  updateLED(4, 0, 0, 0, ledBrightness);
}
void pushZEHN() {
  updateLED(10, 0, 0, 0, ledBrightness);
  updateLED(9, 0, 0, 0, ledBrightness);
  updateLED(8, 0, 0, 0, ledBrightness);
  updateLED(7, 0, 0, 0, ledBrightness);
}
void pushELF() {
  updateLED(60, 0, 0, 0, ledBrightness);
  updateLED(61, 0, 0, 0, ledBrightness);
  updateLED(62, 0, 0, 0, ledBrightness);
}
void pushUHR() {
  updateLED(2, 0, 0, 0, ledBrightness);
  updateLED(1, 0, 0, 0, ledBrightness);
  updateLED(0, 0, 0, 0, ledBrightness);
}
void pushHeart() {
  updateLED(101, ledBrightness, 0, 0, 0);
  updateLED(102, ledBrightness, 0, 0, 0);
  updateLED(106, ledBrightness, 0, 0, 0);
  updateLED(107, ledBrightness, 0, 0, 0);
  updateLED(97, ledBrightness, 0, 0, 0);
  updateLED(94, ledBrightness, 0, 0, 0);
  updateLED(92, ledBrightness, 0, 0, 0);
  updateLED(89, ledBrightness, 0, 0, 0);
  updateLED(77, ledBrightness, 0, 0, 0);
  updateLED(82, ledBrightness, 0, 0, 0);
  updateLED(87, ledBrightness, 0, 0, 0);
  updateLED(76, ledBrightness, 0, 0, 0);
  updateLED(66, ledBrightness, 0, 0, 0);
  updateLED(55, ledBrightness, 0, 0, 0);
  updateLED(65, ledBrightness, 0, 0, 0);
  updateLED(53, ledBrightness, 0, 0, 0);
  updateLED(45, ledBrightness, 0, 0, 0);
  updateLED(35, ledBrightness, 0, 0, 0);
  updateLED(41, ledBrightness, 0, 0, 0);
  updateLED(29, ledBrightness, 0, 0, 0);
  updateLED(25, ledBrightness, 0, 0, 0);
  updateLED(17, ledBrightness, 0, 0, 0);
  updateLED(15, ledBrightness, 0, 0, 0);
  updateLED(5, ledBrightness, 0, 0, 0);
}
void pushTempDegree() {
  updateLED(108, 0, 0, 0, ledBrightness);
  updateLED(90, 0, 0, 0, ledBrightness);
  updateLED(88, 0, 0, 0, ledBrightness);
  updateLED(86, 0, 0, 0, ledBrightness);
}
void pushTempLOne() {
  updateLED( 73 , 0, 0, 0, ledBrightness);
  updateLED( 57 , 0, 0, 0, ledBrightness);
  updateLED( 58 , 0, 0, 0, ledBrightness);
  updateLED( 53 , 0, 0, 0, ledBrightness);
  updateLED( 51 , 0, 0, 0, ledBrightness);
  updateLED( 36 , 0, 0, 0, ledBrightness);
  updateLED( 29 , 0, 0, 0, ledBrightness);
  updateLED( 14 , 0, 0, 0, ledBrightness);
}
void pushTempLTwo() {
  updateLED( 75 , 0, 0, 0, ledBrightness);
  updateLED( 74 , 0, 0, 0, ledBrightness);
  updateLED( 73 , 0, 0, 0, ledBrightness);
  updateLED( 58 , 0, 0, 0, ledBrightness);
  updateLED( 53 , 0, 0, 0, ledBrightness);
  updateLED( 52 , 0, 0, 0, ledBrightness);
  updateLED( 51 , 0, 0, 0, ledBrightness);
  updateLED( 34 , 0, 0, 0, ledBrightness);
  updateLED( 31 , 0, 0, 0, ledBrightness);
  updateLED( 12 , 0, 0, 0, ledBrightness);
  updateLED( 13 , 0, 0, 0, ledBrightness);
  updateLED( 14 , 0, 0, 0, ledBrightness);
}
void pushTempLThree() {
  updateLED( 75 , 0, 0, 0, ledBrightness);
  updateLED( 74 , 0, 0, 0, ledBrightness);
  updateLED( 73 , 0, 0, 0, ledBrightness);
  updateLED( 58 , 0, 0, 0, ledBrightness);
  updateLED( 53 , 0, 0, 0, ledBrightness);
  updateLED( 52 , 0, 0, 0, ledBrightness);
  updateLED( 51 , 0, 0, 0, ledBrightness);
  updateLED( 36 , 0, 0, 0, ledBrightness);
  updateLED( 29 , 0, 0, 0, ledBrightness);
  updateLED( 12 , 0, 0, 0, ledBrightness);
  updateLED( 13 , 0, 0, 0, ledBrightness);
  updateLED( 14 , 0, 0, 0, ledBrightness);
}
void pushTempLFour() {
  updateLED( 75 , 0, 0, 0, ledBrightness);
  updateLED( 73 , 0, 0, 0, ledBrightness);
  updateLED( 56 , 0, 0, 0, ledBrightness);
  updateLED( 58 , 0, 0, 0, ledBrightness);
  updateLED( 53 , 0, 0, 0, ledBrightness);
  updateLED( 52 , 0, 0, 0, ledBrightness);
  updateLED( 51 , 0, 0, 0, ledBrightness);
  updateLED( 36 , 0, 0, 0, ledBrightness);
  updateLED( 29 , 0, 0, 0, ledBrightness);
  updateLED( 14 , 0, 0, 0, ledBrightness);
}
void pushTempRZero() {
  updateLED( 71 , 0, 0, 0, ledBrightness);
  updateLED( 70 , 0, 0, 0, ledBrightness);
  updateLED( 69 , 0, 0, 0, ledBrightness);
  updateLED( 60 , 0, 0, 0, ledBrightness);
  updateLED( 62 , 0, 0, 0, ledBrightness);
  updateLED( 49 , 0, 0, 0, ledBrightness);
  updateLED( 47 , 0, 0, 0, ledBrightness);
  updateLED( 38 , 0, 0, 0, ledBrightness);
  updateLED( 40 , 0, 0, 0, ledBrightness);
  updateLED( 27 , 0, 0, 0, ledBrightness);
  updateLED( 25 , 0, 0, 0, ledBrightness);
  updateLED( 16 , 0, 0, 0, ledBrightness);
  updateLED( 17 , 0, 0, 0, ledBrightness);
  updateLED( 18 , 0, 0, 0, ledBrightness);
}
void pushTempROne() {
  updateLED( 69 , 0, 0, 0, ledBrightness);
  updateLED( 61 , 0, 0, 0, ledBrightness);
  updateLED( 62 , 0, 0, 0, ledBrightness);
  updateLED( 49 , 0, 0, 0, ledBrightness);
  updateLED( 47 , 0, 0, 0, ledBrightness);
  updateLED( 40 , 0, 0, 0, ledBrightness);
  updateLED( 25 , 0, 0, 0, ledBrightness);
  updateLED( 18 , 0, 0, 0, ledBrightness);
}
void pushTempRTwo() {
  updateLED( 71 , 0, 0, 0, ledBrightness);
  updateLED( 70 , 0, 0, 0, ledBrightness);
  updateLED( 69 , 0, 0, 0, ledBrightness);
  updateLED( 62 , 0, 0, 0, ledBrightness);
  updateLED( 49 , 0, 0, 0, ledBrightness);
  updateLED( 48 , 0, 0, 0, ledBrightness);
  updateLED( 47 , 0, 0, 0, ledBrightness);
  updateLED( 38 , 0, 0, 0, ledBrightness);
  updateLED( 27 , 0, 0, 0, ledBrightness);
  updateLED( 16 , 0, 0, 0, ledBrightness);
  updateLED( 17 , 0, 0, 0, ledBrightness);
  updateLED( 18 , 0, 0, 0, ledBrightness);
}
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

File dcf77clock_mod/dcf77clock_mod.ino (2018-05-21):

/**
   Arduino DCF77 decoder v0.2
   Copyright (C) 2006 Mathias Dalheimer (md@gonium.net)

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
   You should have received a copy of the GNU General Public License along
   with this program; if not, write to the Free Software Foundation, Inc.,
   51 Franklin Street, Fifth Floor, Boston, MA 02110-1301 USA.
*/
#include <Wire.h> //https://www.arduino.cc/en/Reference/Wire
#include <LiquidCrystal_I2C.h> //https://github.com/fdebrabander/Arduino-LiquidCrystal-I2C-library
/* ************** LCD BLOCK ************** */
// Set the LCD address to 0x27 for a 16 chars and 2 line display
LiquidCrystal_I2C lcd(0x27, 16, 2);


/**
   Where is the DCF receiver connected?
*/
#define DCF77PIN 2
/**
   Where is the LED connected?
*/
#define BLINKPIN 13
/**
   Turn debugging on or off
*/
#define DCF_DEBUG 1
/**
   Number of milliseconds to elapse before we assume a "1",
   if we receive a falling flank before - its a 0.
*/
#define DCF_split_millis 140
/**
   There is no signal in second 59 - detect the beginning of
   a new minute.
*/
#define DCF_sync_millis 1200
/**
   Definitions for the timer interrupt 2 handler:
   The Arduino runs at 16 Mhz, we use a prescaler of 64 -> We need to
   initialize the counter with 6. This way, we have 1000 interrupts per second.
   We use tick_counter to count the interrupts.
*/
#define INIT_TIMER_COUNT 6
#define RESET_TIMER2 TCNT2 = INIT_TIMER_COUNT
int tick_counter = 0;
int TIMSK;
int TCCR2;
int OCIE2;
/**
   DCF time format struct
*/
struct DCF77Buffer {
  unsigned long long prefix	: 21;
  unsigned long long Min	: 7;	// minutes
  unsigned long long P1		: 1;	// parity minutes
  unsigned long long Hour	: 6;	// hours
  unsigned long long P2		: 1;	// parity hours
  unsigned long long Day	: 6;	// day
  unsigned long long Weekday	: 3;	// day of week
  unsigned long long Month	: 5;	// month
  unsigned long long Year	: 8;	// year (5 -> 2005)
  unsigned long long P3		: 1;	// parity
};
struct {
  unsigned char parity_flag	: 1;
  unsigned char parity_min		: 1;
  unsigned char parity_hour	: 1;
  unsigned char parity_date	: 1;
} flags;
/**
   Clock variables
*/
volatile unsigned char DCFSignalState = 0;
unsigned char previousSignalState;
int previousFlankTime;
int bufferPosition;
unsigned long long dcf_rx_buffer;
/**
   time vars: the time is stored here!
*/
volatile unsigned char ss;
volatile unsigned char mm;
volatile unsigned char hh;
volatile unsigned char day;
volatile unsigned char mon;
volatile unsigned int year;


/**
   used in main loop: detect a new second...
*/
unsigned char previousSecond;

/**
   Initialize the DCF77 routines: initialize the variables,
   configure the interrupt behaviour.
*/
void DCF77Init() {
  previousSignalState = 0;
  previousFlankTime = 0;
  bufferPosition = 0;
  dcf_rx_buffer = 0;
  ss = mm = hh = day = mon = year = 0;
#ifdef DCF_DEBUG
  Serial.println("Initializing DCF77 routines");
  Serial.print("Using DCF77 pin #");
  Serial.println(DCF77PIN);
  pinMode(BLINKPIN, OUTPUT);
  pinMode(DCF77PIN, INPUT);
#endif
  pinMode(DCF77PIN, INPUT);
#ifdef DCF_DEBUG
  Serial.println("Initializing timerinterrupt");
#endif
  //Timer2 Settings: Timer Prescaler /64,
  TCCR2 |= (1 << CS22);  // turn on CS22 bit
  TCCR2 &= ~((1 << CS21) | (1 << CS20)); // turn off CS21 and CS20 bits
  // Use normal mode
  TCCR2 &= ~((1 << WGM21) | (1 << WGM20)); // turn off WGM21 and WGM20 bits
  // Use internal clock - external clock not used in Arduino
  ASSR |= (0 << AS2);
  TIMSK |= (1 << TOIE2) | (0 << OCIE2);    //Timer2 Overflow Interrupt Enable
  RESET_TIMER2;
#ifdef DCF_DEBUG
  Serial.println("Initializing DCF77 signal listener interrupt");
#endif
  attachInterrupt(0, int0handler, CHANGE);
}

/**
   Append a signal to the dcf_rx_buffer. Argument can be 1 or 0. An internal
   counter shifts the writing position within the buffer. If position > 59,
   a new minute begins -> time to call finalizeBuffer().
*/
void appendSignal(unsigned char signal) {
#ifdef DCF_DEBUG
  Serial.print(", appending value ");
  Serial.print(signal, DEC);
  Serial.print(" at position ");
  Serial.println(bufferPosition);
#endif
  dcf_rx_buffer = dcf_rx_buffer | ((unsigned long long) signal << bufferPosition);
  // Update the parity bits. First: Reset when minute, hour or date starts.
  if (bufferPosition ==  21 || bufferPosition ==  29 || bufferPosition ==  36) {
    flags.parity_flag = 0;
  }
  // save the parity when the corresponding segment ends
  if (bufferPosition ==  28) {
    flags.parity_min = flags.parity_flag;
  };
  if (bufferPosition ==  35) {
    flags.parity_hour = flags.parity_flag;
  };
  if (bufferPosition ==  58) {
    flags.parity_date = flags.parity_flag;
  };
  // When we received a 1, toggle the parity flag
  if (signal == 1) {
    flags.parity_flag = flags.parity_flag ^ 1;
  }
  bufferPosition++;
  if (bufferPosition > 59) {
    finalizeBuffer();
  }
}

/**
   Evaluates the information stored in the buffer. This is where the DCF77
   signal is decoded and the internal clock is updated.
*/
void finalizeBuffer(void) {
  if (bufferPosition == 59) {
#ifdef DCF_DEBUG
    Serial.println("Finalizing Buffer");
#endif
    struct DCF77Buffer *rx_buffer;
    rx_buffer = (struct DCF77Buffer *)(unsigned long long)&dcf_rx_buffer;
    if (flags.parity_min == rx_buffer->P1  &&
        flags.parity_hour == rx_buffer->P2  &&
        flags.parity_date == rx_buffer->P3)
    {
#ifdef DCF_DEBUG
      Serial.println("Parity check OK - updating time.");
#endif
      //convert the received bits from BCD
      mm = rx_buffer->Min - ((rx_buffer->Min / 16) * 6);
      hh = rx_buffer->Hour - ((rx_buffer->Hour / 16) * 6);
      day = rx_buffer->Day - ((rx_buffer->Day / 16) * 6);
      mon = rx_buffer->Month - ((rx_buffer->Month / 16) * 6);
      year = 2000 + rx_buffer->Year - ((rx_buffer->Year / 16) * 6);
    }
#ifdef DCF_DEBUG
    else {
      Serial.println("Parity check NOK - running on internal clock.");
    }
#endif
  }
  // reset stuff
  ss = 0;
  bufferPosition = 0;
  dcf_rx_buffer = 0;
}

/**
   Dump the time to the serial line.
*/
void serialDumpTime(void) {
  Serial.print("Time: ");
  Serial.print(hh, DEC);
  Serial.print(":");
  Serial.print(mm, DEC);
  Serial.print(":");
  Serial.print(ss, DEC);
  Serial.print(" Date: ");
  Serial.print(day, DEC);
  Serial.print(".");
  Serial.print(mon, DEC);
  Serial.print(".");
  Serial.println(year, DEC);

  //  lcd.setCursor( 0, 1);
  //  lcd.print( String(hh) +":"+ String(mm) +":"+ String(ss) +"_"+ String(day) +"."+ String(mon) +"."+ String(year) );
}
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

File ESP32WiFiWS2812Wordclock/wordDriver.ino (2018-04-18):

#include "default_layout.h"

void pushToStrip(int ledId);

void pushToStrip(int ledId) {
  
    pixels[ledId] = makeRGBVal(227, 220, 128);
    ws2812_setColors(NUM_PIXELS, pixels);
}

void displayOff() {
  for (int i = 0; i < NUM_PIXELS; i++) {
    pixels[i] = makeRGBVal(0, 0, 0);
  }
  ws2812_setColors(NUM_PIXELS, pixels);
}

void matrixReloaded(){
  int matrix [10] [11] = {
  //[10]Zeilen [11]Spalten
 {99, 100, 101, 102, 103, 104, 105, 106, 107, 108, 109},
 {98,  97,  96,  95,  94,  93,  92,  91,  90,  89,  88},
 {77,  78,  79,  80,  81,  82,  83,  84,  85,  86,  87},
 {76,  75,  74,  73,  72,  71,  70,  69,  68,  67,  66},
 {55,  56,  57,  58,  59,  60,  61,  62,  63,  64,  65},
 {54,  53,  52,  51,  50,  49,  48,  47,  46,  45,  44},
 {33,  34,  35,  36,  37,  38,  39,  40,  41,  42,  43},
 {32,  31,  30,  29,  28,  27,  26,  25,  24,  23,  22},
 {11,  12,  13,  14,  15,  16,  17,  18,  19,  20,  21},
 {10,   9,   8,   7,   6,   5,   4,   3,   2,   1,   0}
};

for(int y = 0; y< 11; y++){
  for (int i = 0; i < 10; i++) {
    pixels[ matrix[i][y] ] = makeRGBVal(0, 100, 0);
    ws2812_setColors(NUM_PIXELS, pixels);
    pixels[ matrix[i][y-1] ] = makeRGBVal(0, 0, 0);
  }
  
}

}


void displayStars(){
  int  i = random(NUM_PIXELS);
  pixels[i] = makeRGBVal (255, 0, 0);
  ws2812_setColors(NUM_PIXELS, pixels);
  delay(1);
  displayOff();
}

void pushES_IST()  {
	pushToStrip(L99);
	pushToStrip(L100);
	pushToStrip(L102);
	pushToStrip(L103);
	pushToStrip(L104);
}

void pushFUENF1() {
	pushToStrip(L106);
	pushToStrip(L107);
	pushToStrip(L108);
	pushToStrip(L109);
}

void pushFUENF2() {
	pushToStrip(L62);
	pushToStrip(L63);
	pushToStrip(L64);
	pushToStrip(L65);
}

void pushNACH() {
	pushToStrip(L69);
	pushToStrip(L68);
	pushToStrip(L67);
	pushToStrip(L66);
}

void pushZEHN1() {
	pushToStrip(L98);
	pushToStrip(L97);
	pushToStrip(L96);
	pushToStrip(L95);
}

void pushVIERTEL() {
	pushToStrip(L81);
	pushToStrip(L82);
	pushToStrip(L83);
	pushToStrip(L84);
	pushToStrip(L85);
	pushToStrip(L86);
	pushToStrip(L87);
}

void pushVOR() {
	pushToStrip(L76);
	pushToStrip(L75);
	pushToStrip(L74);
}

void pushHALB() {
	pushToStrip(L55);
	pushToStrip(L56);
	pushToStrip(L57);
	pushToStrip(L58);
}

void pushONE() {
	pushToStrip(L111);
}

void pushTWO() {
	pushToStrip(L110);
}

void pushTHREE() {
	pushToStrip(L113);
}

void pushFOUR() {
	pushToStrip(L112);
}

void pushZWANZIG() {
	pushToStrip(L94);
	pushToStrip(L93);
	pushToStrip(L92);
	pushToStrip(L91);
	pushToStrip(L90);
	pushToStrip(L89);
	pushToStrip(L88);
}

void pushZWOELF() {
	pushToStrip(L17);
	pushToStrip(L18);
	pushToStrip(L19);
	pushToStrip(L20);
	pushToStrip(L21);
}

void pushEINS(bool s) {
	pushToStrip(L54);
	pushToStrip(L53);
	pushToStrip(L52);
	if(s) {
		pushToStrip(L51);
	}
}

void pushZWEI() {
	pushToStrip(L47);
	pushToStrip(L46);
	pushToStrip(L45);
	pushToStrip(L44);
}

void pushDREI() {
	pushToStrip(L33);
	pushToStrip(L34);
	pushToStrip(L35);
	pushToStrip(L36);
}

void pushVIER() {
	pushToStrip(L40);
	pushToStrip(L41);
	pushToStrip(L42);
	pushToStrip(L43);
}

void pushSECHS() {
	pushToStrip(L32);
	pushToStrip(L31);
	pushToStrip(L30);
	pushToStrip(L29);
	pushToStrip(L28);
}

void pushSIEBEN() {
	pushToStrip(L11);
	pushToStrip(L12);
	pushToStrip(L13);
	pushToStrip(L14);
	pushToStrip(L15);
	pushToStrip(L16);
}

void pushACHT() {
	pushToStrip(L25);
	pushToStrip(L24);
	pushToStrip(L23);
	pushToStrip(L22);
}

void pushNEUN() {
	pushToStrip(L7);
	pushToStrip(L6);
  pushToStrip(L5);
	pushToStrip(L4);
}

void pushZEHN() {
	pushToStrip(L10);
	pushToStrip(L9);
	pushToStrip(L8);
	pushToStrip(L7);
}

void pushELF() {
	pushToStrip(L60);
	pushToStrip(L61);
	pushToStrip(L62);
}
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

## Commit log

2018-04-18 ADD EXCEL TABLE
    [Frontplatte.xlsx]
2018-04-18 Schiebe excel
    [Frontplatte.xlsx]
2018-05-13 Changes: Lib def. / Mode Selector
    -Add required adafruit sensor lib
    -Add LEDPIN as a constant (better for reading)
    -State machine numbers replaced with constant
    [SchlendrickWordClockV2.ino]
2018-05-14 Add dxf files with Readme
    [Wortuhr_rahmen_back.dxf, Wortuhr_rahmen_front_ws2812b.dxf]
2018-05-16 Update Arduino Nano
2018-05-21 Add Gehäuse dxf and Frontplatte Laser Vorlage
    [500x500_CLT_DE_Laser_1.dxf, 500x500_CLT_DE_Laser_2.dxf, 500x500_CLT_DE_Laser_3.dxf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]

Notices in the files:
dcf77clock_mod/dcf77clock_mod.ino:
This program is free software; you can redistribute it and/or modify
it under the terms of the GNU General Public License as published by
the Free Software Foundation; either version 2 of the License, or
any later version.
